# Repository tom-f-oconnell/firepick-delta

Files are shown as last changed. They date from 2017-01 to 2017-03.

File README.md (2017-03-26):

#### Summary / Context

Design and Manufacturing Specifications for [FirePick Delta](http://delta.firepick.org).  If you're a developer wanting to help, the best way to do that is to join the [mailing list](https://groups.google.com/forum/#!forum/firepick) and start a line of communication there.  

This repo only contains the hardware (sch/pcb) and mechanical (3d) files for FirePick Delta.  It inherits software from OpenPnP, Marlin, and FirePick.  Other repo's of interest for FirePick Delta:

* https://github.com/firepick-delta/openpnp
* https://github.com/firepick-delta/Marlin
* https://github.com/firepick1/FireREST
* https://github.com/firepick1/FireBOM

#### Mechanical Assembly Parts Tree, Instructions, and BOM

Please click the link below to navigate the mechanical assembly with our FireBOM wiki documentation system:

[AFPD0001](AFPD0001) FirePick Delta Hacker-Developer Edition

#### Licensing

CC-BY-SA

These files are licensed under [*Creative Commons Attribution-ShareAlike (CC BY-SA)*](https://creativecommons.org/licenses/by-sa/4.0/legalcode).  Commercial use is OK, but you are required under the license conditions to share your changes with the internet, and also credit the FirePick Delta team.

This license lets others remix, tweak, and build upon your work even for commercial purposes, as long as they credit you and license their new creations under the identical terms. This license is often compared to “copyleft” free and open source software licenses. All new works based on yours will carry the same license, so any derivatives will also allow commercial use. This is the license used by Wikipedia, and is recommended for materials that would benefit from incorporating content from Wikipedia and similarly licensed projects. 

[View License Deed](http://creativecommons.org/licenses/by-sa/4.0/) | [View Legal Code](https://creativecommons.org/licenses/by-sa/4.0/legalcode)

#### Contributors
* [@FlyingLotus1983 (Neil Jansen)](https://github.com/FlyingLotus1983)
* [@firepick1 (Karl Lew)](https://github.com/firepick1)
* [@ChristianLerche (Christian Lerche)](https://github.com/ChristianLerche)
* [@daytonpid (Dayton Pidhirney)](https://github.com/daytonpid)
* [@codedetail (Dave Shanklin)](https://github.com/codedetail)
* [@obnauticus (Thomas Kilbride)](https://github.com/obnauticus)
* [@mstegen (Mike Stegen)](https://github.com/mstegen)
* [@mikeanton (Mike Anton)](https://github.com/mikeanton)

#### Maintainers
* [@FlyingLotus1983 (Neil Jansen)](https://github.com/FlyingLotus1983)
* [@firepick1 (Karl Lew)](https://github.com/firepick1)

#### Contributions and Pull Requests

If you'd like to contribute anything back to this repo, please do so via [pull requests](https://help.github.com/articles/using-pull-requests).  

Keep in mind that the Cubify Design files are binary blobs.  Assembly (AD_ASM) files contain filepath links back to dependent solid parts (AD_PRT), and parts contain filepath links back to the assembly.  This makes it extremely tricky to use version control.  You can't just rename files all willy-nilly, or else Cubify will get very angry.  Please excercise caution and contact the FirePick Delta Dev Team via [google group mailing list](https://groups.google.com/forum/#!forum/firepick) before attempting to modify anything of significant nature.

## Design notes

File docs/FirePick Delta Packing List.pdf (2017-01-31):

# Preliminary BOM for FirePick Delta

## Beta Test Kits - Round 1

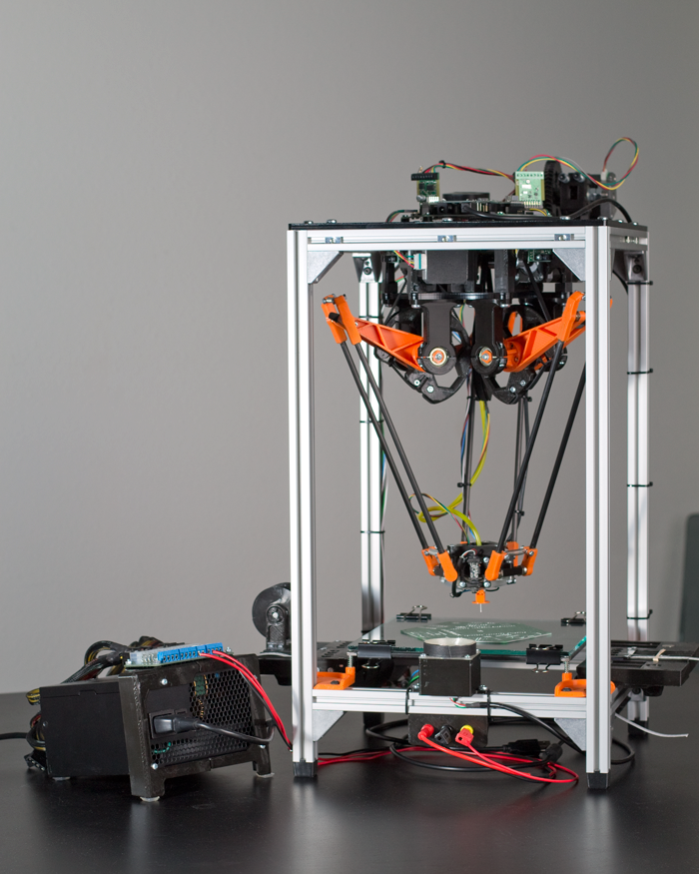
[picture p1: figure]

## Published May 6, 2015

## Heated Bed Assembly

| Part Number | Quantity | Description | Purpose | Barebones?

## Hardware Bag 1

| FBHCS-M5-10L | 8 | Fastener, M5 button-head cap screw, 10mm L | Bed leveling corners | NO
| FFLT-M3-10L | 4 | Fastener, M3 flat-head machine screw, 10mm L | Heated bed PCB attachment | NO
| FNUT-M3 | 4 | Fastener, M3 nut | Heated bed PCB attachment | NO
| FNUT-M4 | 4 | Fastener, M4 nut | Bed leveling corners | NO
| FNUT-M5-HNKK5 | 8 | Extrusion nut, M5 | Attachment to frame extrusion | NO
| FSHCS-M4-30L | 4 | Fastener, M4 socket head cap screw, 30mm L | Bed leveling corners | NO
| FWSH-M3 | 4 | Fastener, M3 flat washer | Heated bed PCB attachment | NO
| FWSH-M4 | 12 | Fastener, M4 flat washer | Bed leveling corners | NO
| MSPRING01 | 4 | Spring, bed leveling | Leveling springs for heated bed | YES
| MCLIP01 | 4 | MCLIP01 - Metal clip for heated bed to glass | Attaches glass to heated bed surface | YES
| MMAG01 | 6 | Magnet, 1/2" dia. x 3/8" L | Install in 3D0028 to act as "pucks" for PCB holding to steel bed | YES
| Zip ties | TBD | 0.1" wide x 6" | Wire management | NO
| N/A | 30" | Wire, twisted pair, heated bed thermistor | Thermistor to EAT0002 wiring | NO
| N/A | 30" | Wire, 18 AWG, yellow, heated bed (ATX power supply '+12V2' to bed) | Heated bed power wiring (~10A) | NO
| N/A | 30" | Wire, 18 AWG, Black, heated bed (EAT0002 to bed) | Heated bed power wiring (~10A) | NO
| N/A | 50" | Wire, 18 AWG, Black, heated bed (EAT0002 to ATX power supply 'GND') | Heated bed power ground wiring (~10A) | NO
| N/A | 2 | Ferrule, thermistor to twisted pair | Ferrule crimps are more reliable than soldering these connections | NO

## Electronics

| EAT0002 | 1 | Modular tool PCB | Connects modular tool to EMC02 | YES
| EL-THERMISTOR | 1 | Thermistor, for heated bed | Temperature sensing element for 3D printing heated bed | NO
| EHB01 | 1 | PCB heated bed | Heated bed for 3d printing | NO

## 3D Printed Pieces

| 3D0052 | 4 | Heated Bed Bracket | Attachment points for the heated bed assembly to the frame | NO
| 3D0028 | 6 | PCB magnet holder | Magnetic "pucks" for holding PCBs | NO

## Plates / Panels

| PG01 | 1 | Glass plate, 1/8" (3mm) x 200mm x 200mm | Glass plate for flat, even surface to print on | YES
| PS01 | 1 | Bed plate, low-carbon steel, waterjet cut | Modular bed that provides magnetic attachment points for SMT PCBs via AD0017 "pucks". Also provides a heat spreading functionality for the heated bed | YES

## Frame Assembly

## Hardware Bag 1

| FBHCS-M5-10L | 48 | Fastener, M5 button-head cap screw, 10mm L | Fasteners for frame extrusion pieces | NO
| FNUT-M5-HNKK | 37 | Extrusion nut, M5 | Holds aluminum extrusion frame peices togeth | NO
| FWSH-M5-SPLIT | 32 | Fastener, M5 flat washer | Fasteners for frame extrusion pieces | NO
| 3D0025 | 4 | Extrusion foot, cast rubber | Custom rubber feet for bottom of machine fra | YES

## Hardware Bag 2 (Brackets)

| XEB505 | 16 | Extrusion 45 degree angle bracket | Corner brackets for frame | NO

## Plates / Panels

| PC01 | 1 | Top plate, acrylic laser cut | Mounting plate for delta mechanism | YES

## Extrusions

| XE2020-260 | 8 | Extrusion, 20x20mm, 260mm long | Horizontal extrusions for frame | NO
| XE2020-500 | 4 | Extrusion, 20x20mm, 500mm long | Vertical extrusions for frame | NO

### Delta Mechanism

| Part Number | Quantity | Description | | Barebones?

### Hardware Bag 1

| DB608 | 6 | Bearing, 608 | Ball bearings for delta arms | NO
| DGB383 | 3 | GT2 belt, 383mm L | NOTE: This may be in one continuous length rather than three separate pieces | NO
| DGP16T | 3 | GT2 pulley, 16 teeth, 5mm bore | Aluminum pulley goes on end of NEMA 17 stepper motor | NO
| FSET-M3-6L | 6 | Fastener, M3 set screw | NOTE: These may already be in the 16T GT2 pulley | NO
| FBHCS-M5-14L | 12 | Fastener, M5 button-head cap screw, 14mm L | These connect the 3D00456 stepper mounts to the frame PC01 plate. | NO
| FBHCS-M5-20L | 12 | Fastener, M5 button-head cap screw, 20mm L | These connect the 3D0001a bearing blocks to the 3D00456 stepper mounts | NO
| FFLT-M3-12L | 3 | Fastener, M3 flat-head machine screw, 12mm L | This fastener holds the GT2 belt to the 150T pulley. | NO
| FNUT-M3 | 54 | Fastener, M3 nut | | NO
| FNUT-M5 | 24 | Fastener, M5 nut | Go inside 3D00456 nut traps | NO
| FPAN-M3-10L | 12 | Fastener, M3 pan-head machine screw, 10mm L | | NO
| FPAN-M3-12L | 3 | Fastener, M3 pan-head machine screw, 12mm L | This fastener holds the GT2 belt to the 150T pulley. | NO
| FPAN-M3-20L | 21 | Fastener, M3 pan-head machine screw, 20mm L | 12 are used to attach the 608 bearing block caps 6 are used to attach the EOPTO01 to the 3D00456. 3 are used to attach the 3D0007 optical interruptors to the 3D0003a delta arms | NO
| FPAN-M3-30L | 12 | Fastener, M3 pan-head machine screw, 30mm L | These hold the 3D0003a arms to the 3D0002b pulleys | NO
| FPAN-M3-50L | 6 | Fastener, M3 pan-head machine screw, 50mm L | These hold the 3D0003b nuts to the 608 bearings and the 3D0003a delta arms | NO
| FWSH-M3 | 6 | Fastener, M3 flat washer | These go between the 3D0003b nuts and the 608 bearings on the delta arm assemblies | NO

### Hardware Bag #2

| DBS-0.375-10L-HEX | 6 | Ball stud, 3/8" dia, M3x10 | Delta mechanism bearings | YES

### Plates / Panels

| PC03a | 1 | Delta motor plate (Acrylic laser-cut) | Center plate between motors and delta pulleys/arms/bearings | YES

### Electronics

| EOPTO01 | 3 | Optical endstop board | Homing switches (these are optical interruptor type) | YES

### 3D Printed Pieces

| 3D0001a | 6 | Delta motor Assembly - 608 bearing block | Black. Bearing blocks for delta arms. | NO
| 3D0002b | 3 | Delta motor assembly - Pulley, 150 teeth | Black. Large pulley connected to 3D0003a/b arms | NO
| 3D0003a | 6 | Delta motor assembly - Delta arm 90mm | Orange. Delta mechanism upper arm | NO
| 3D0003b | 6 | Delta motor assembly - Delta arm 90mm nut | Orange. Nut to allow 608 bearings to be attached to 3D0003a via M3 hardware. | NO
| 3D0004 | 6 | Delta motor Assembly - 608 bearing block caps | Black. Caps for bearing blocks. | NO
| 3D0007 | 3 | Delta motor assembly - Limit switch interruptor | Black. This is attached between the 3D0003a arms and acts as an interruptor to the optical limit switch | NO
| 3D0456 | 3 | Delta stepper mount | Black. Mounts steppers to PC01 and PC03a middle plate | NO

### Big heavy stuff

| EM-ST17 | 3 | Stepper motor, NEMA 17 | Stepper motors for delta mechanism | NO

## Motion Controller Assembly

## Hardware Bag 1

| FNUT-M3 | 14 | FNUT-M3 | 6 go in the 3D0021, 8 go in the 3D0015a | NO
| FPAN-M3-25L | 6 | FPAN-M3-25L | For attaching PC04a to EMC02 and the PC01 panel via standoffs | NO
| FPAN-M3-20L | 8 | FPAN-M3-20L | Fasteners for 3D0021 and PC04a | NO

## Electronics

| EMC02 | 1 | EMC02 motion controller board | Motion controller breakout board | YES
| N/A | 17 | Shunt / Shorting jumper, 0.1" | Configuration jumpers for EMC02 module | YES
| EL-ARDUINO-MEGA256 | 1 | Arduino Mega 2560 | Microprocessor loaded with Arduino / Marlin firmware | NO
| N/A | 1 | USB cable, "A" to "B" | For Arduino | NO
| EL-STEPSTICK | 3 | Stepstick (stepper motor driver module) | Stepper motor driver module | YES

## Wiring

| N/A | 3 | Stepper motor cable, 4-pin, ~145mm | | NO
| N/A | 3 | Endstop cable, ~95mm L | | NO

## 3D Printed Pieces

| 3D0021 | 4 | EMC01 Modular tool card-cage | Card cage for the modular tools. Prevents them from being plugged in backwards, and provides mechanical integrity | NO
| 3D0015a | 3 | EMC02 mounting plate | Provides a | NO
| FSTN-M3-16L-UNTHRE | 6 | Standoffs (spacers) | For mounting the PC04a plate onto the EMC02 assembly | NO

## Plates / Panels

| PC04a | 1 | EMC02 cover plate, laser cut acrylic | Cover plate | YES

| FPAN-M5-8L | 2 | Fastener, M5 pan-head machine screw, 8mm L | These attach the up-looking camera module to the frame | NO
| FPAN-M3-8L | 4 | Fastener, M3 pan-head machine screw, 8mm L | These attach the LED diffuser ring to the camera module housing | NO
| FPAN-M2-8L | 4 | Fastener, M2 pan-head machine screw, 8mm L | These attach the camera module to the housing | NO
| FNUT-M3 | 4 | Fastener, M3 nut | These attach the LED diffuser ring to the camera module housing | NO
| FNUT-M2 | 4 | Fastener, M2 nut | These attach the camera module to the housing | NO
| FNUT-M5-HNKK5 | 2 | Extrusion nut, M5 | These attach the up-looking camera module to the frame | NO
| N/A | 42" | Wire, 24 AWG, red | Up-looking camera LED ring +5V power | NO
| N/A | 42" | Wire, 24 AWG, black | Up-looking camera LED ring GND | NO
| N/A | 42" | Wire, 24 AWG, white | Up-looking camera LED ring ON signal | NO
| N/A | 6 | Crimp pin, 0.1" for rectangular header | Crimp pin for cable | NO
| N/A | 2 | Rectangular header, 3-pin non-polarized | Rectangular housing for cable | NO
| N/A | 7 | Zip ties, 0.1" wide (long enough to zip tie to frame) | Cable management | NO

### 3D printed parts

| 3D0026b | 1 | Up-looking camera housing base (black PLA) | Provides an enclosure for the camera, with an attach point for an LED ring light | NO
| 3D0030b | 1 | Up-looking camera housing diffuser (clear / natural PLA) | Acts as a diffuser for the ring light. Attaches to the 3D0026b base. | NO

### Electronics

| EL-CAM-ELP-USB100W03M | 1 | EL-CAM-ELP-USB100W03M | Up-looking camera module. | YES
| N/A | 1 | USB cable for the ELP camera | This USB cable should be included with the ELP camera. | YES

### ELED02 Ring Light Kit

| ELED02 | 1 | Up-looking camera ring light PCB | LED Ring light for improving down-looking camera effectiveness. Note:
| N/A | 16 | LED, 1206, red | This is a kit intended to be used during the testing phases of the SMT pick and place functionality of the machine.
| N/A | 8 | Resistor, 0805, 120 ohm
| N/A | 1 | MOSFET, SOT-23, BSS138 | | YES
| N/A | 1 | Resistor, 10K
| N/A | 1 | Capacitor, 100 uF
| N/A | 1 | Rectangular header, male, right-angle, 3-pin, 0.1" offset

### Up-Looking Camera

| FNUT-M5-HNKK5 | 2 | Extrusion nut, M5 | Vacuum pump frame mount and clamp | NO
| FPAN-M5-14L | 1 | FPAN-M5-14L | Vacuum pump mount clamp | NO
| FBHCS-M5-14L | 1 | FBHCS-M5-14L | Vacuum pump mount to frame | NO
| DTB-0.0625-0.1875 | 1 | Tubing coupler, barbed, 1/16" to 3/16" | Adapt vacuum pump tubing size down to smaller size | YES
| FFLT-M5-10L | 3 | Fastener, M5 flat-head machine screw, 10mm L | Modular tool changer points | NO
| FNUT-M5 | 3 | Fastener, M5 nut | Modular tool changer points | NO
| FPAN-M2-5L | 4 | Fastener, M2 pan-head machine screw, 5mm L | NEMA 8 motor to 3DAT0021a | NO
Nozzle Bag
| TBD-Large nozzle | 1 | Large nozzle tip, machined 12L40 steel | Vacuum tip for large SMT parts (electrolytic caps, etc) | YES
| TBD-Small nozzle | 1 | Small nozzle tip, machined 12L40 steel | Vacuum tip for small SMT parts (resistors, etc) | YES
| TBD-Coupler | 1 | Coupler, machined aluminum | This is permanently attached to the hollow-shaft NEMA 8 motor, and allows various tips to be installed | YES
| TBD | 1 | Set screw, M3 x 5mm | Used to attach the coupler ot the NEMA 8 hollow shaft motor | YES
| TBD | 1 | O-ring | Goes on the aluminum shaft, provides a lock-fit and air-tight connection between the coupler and the tips | YES

Electromechanical

| EM-ST08-HOLLOW | 1 | Stepper motor, NEMA 8 hollow-shaft | SMT nozzle part rotation | YES
| VP01 | 1 | Diaphragm vacuum pump, 12V | Vacuum source | YES
3D printed parts
| | 1 | Vacuum pump mount | Mount vacuum pump to frame | NO
| 3DAT0021a | 1 | Modular tool mount for SMT, NEMA 8 motor | Holds NEMA 8 motor | NO
Electronics
| EAT0004 | 1 | Modular tool PCB | Connects modular tool to EMC02 | YES
Misc.
| MFOAM01 | 1 | Foam strip | Vibration damper for diaphragm pump | YES
| DTS-0.1875ID-0.3125OD-150L | 1 | Tubing, silicone, 3/16" ID, 5/16" OD, 150mm L | Attaches to diaphragm pump | NO
| DTS-0.0625ID-0.1875OD-500L | 1 | Tubing, silicone, 1/16" ID, 3/16" OD, 500mm L | Attaches to NEMA 8 hollow-shaft motor | NO
| N/A | 18" | Wire, 24 AWG, red | SMT modular tool, NEMA 8 motor extension | NO
| N/A | 18" | Wire, 24 AWG, green | SMT modular tool, NEMA 8 motor extension | NO
| N/A | 18" | Wire, 24 AWG, yellow | SMT modular tool, NEMA 8 motor extension | NO
| N/A | 18" | Wire, 24 AWG, black | SMT modular tool, NEMA 8 motor extension | NO
| N/A | 14" | Wire, 24 AWG, red | SMT modular tool, diaphragm pump | NO
| N/A | 14" | Wire, 24 AWG, black | SMT modular tool, diaphragm pump | NO
| N/A | 1 | Cable, NEMA 8 stepper motor | NOTE: This comes with the NEMA 8 motor | NO
| N/A | 4 | Zip ties | 1x for holding silicone tubing to NEMA 8 motor. 3 for wire management | NO
| N/A | 5mm | Heat shrink tubing - 1" unshrunk | Wrap around stepper motor | NO
| N/A | 3x 10mm | Heat shrink tubing - 1/8" dia unshrunk | Extension wiring on stepper motor cabling | NO
| N/A | 2x 15mm | Heat shrink tubing - 3/16" dia unshrunk | Diaphragm pump wiring | NO

SMT Modular Tool

| FHEX-M8-60L-HOBBED | 1 | Hobbed bolt | Hobbed bolt for the 3d printer extruder (hobbed portion pushes the plastic into the hotend) | NO
| FNUT-M3 | 1 | Fastener, nut, M3 | This goes in the guidler hinge nut trap | NO
| FNUT-M8 | 1 | Fastener, nut, M8 | This goes on the end of the hobbed bolt (NOTE: This is optional, as you can just use the nylock nut, but this will make unscrewing the nylock a lot easier) | NO
| FPAN-M3-25L | 3 | Fastener, M3 pan-head machine screw, 25mm L | 2 for the J-Head groove mount clamp. 1 for the Guidler hinge. | NO
| FPAN-M3-8L | 3 | Fastener, M3 pan-head machine screw, 8mm L | Attaches the NEMA 17 stepper motor to the Wade extruder | NO
| FSET-M8-20L | 1 | Set screw, M8, 20mm L | 608 bearing rotates around this in the guidler | NO
| FWSH-M3-SPLIT | 3 | Fastener, washer, M3, split-lock | Optional; These can be used on the NEMA 17 stepper motor attachment screws to ensure the motor does not vibrate loose | NO
| FWSH-M8 | 1 | Fastener, washer, M8 | This goes on the outside of the 608 bearing, before the M8 nut | NO
| MSPRING01 | 2 | Extruder spring | For the guidler. They go over the FSHCS-M4-60L screws | YES
| FSHCS-M4-60L | 2 | Fastener, socket-head cap screw, M4, 60mm L | Guidler tensioning | NO
| FWSH-M4 | 4 | Fastener, washer, M4 | These go over the FSHCS-M4-60L screws, on both sides of the springs | NO
| FNUT-M4 | 2 | Fastener, nut, M4 | These go into the nut traps in the 3DAT0001a, for the guidler tensioning screws | NO
| FNUT-M8-LOCK | 1 | Fastener, M8, nut, nylock | The M8 lock nut keeps the large herringbone gear and hobbed bolt from coming loose | NO
| FNUT-M5-HNKK5 | 1 | Extrusion nut | This attaches the Wade extruder to the extruded frame | NO
| FBHCS-M5-10L | 1 | Fastener, button-head cap screw, M5, 10mm L | This attaches the Wade extruder to the extruded frame | NO
| VF01 | 2 | Embedded Bowden Couplings - For Plastic (1.75mm Filament) | Bowden tubing push-to-fit connector (1 for Wade extruder, 1 for the modular tool). NOTE: There are two pieces to each fitting: The outside coupling with the spiky barbs, and the fitting that goes inside it | YES
| FFLT-M5-10L | 3 | FFLT-M5-10L | Modular tool changer points | NO
| FNUT-M3 | 2 | FNUT-M3 | Clamp for J-Head groove mount | NO
| FNUT-M5 | 3 | FNUT-M5 | Modular tool changer points | NO
Misc.
| DTPTFE-4OD-2ID-500L | 500mm | Bowden tube, PTFE (Teflon), 4mm OD, 2mm ID | For Bowden tube | NO
| N/A | 30" | Wire, 24 AWG, red | Hotend heating element | NO
| N/A | 30" | Wire, 24 AWG, black | Hotend heating element | NO
| N/A | 30" | Wire, twisted pair, 26-28 AWG | hotend thermistor | NO
| N/A | 2 | Ferrule, thermistor to twisted pair | Because ferrules are more reliable than soldering for this connection | NO
| N/A | 2 | Ferrule, resistor to 24 AWG wire | Because ferrules are more reliable than soldering for this connection | NO
| N/A | 2x | Heat shrink, PTFE (Teflon) | To cover the hotend's crimped ferrules | NO
| N/A | 2x | Heat shrink, for thermistor leads | To cover the thermistor's crimped ferrules | NO
| N/A | 200mm | Kapton tape, ~12mm wide | NOTE: Doesn't ship with the kit | NO
| N/A | 9 | Zip ties (small / 6") | Wire management | NO
| N/A | 2x 35mm | Heat shrink tubing, 3/8" dia | For wiring and bowden tubing securing (both ends) | NO
| N/A | 500mm | Techflex sleeving (optional) | Optional. Covers Bowden tube and wiring | NO
| N/A | 2x 35mm | Fiberglass sleeving | Thermistor wiring / insulation (between glass bead and crimped ferrule) | NO

## Electromechanical

| EM-ST17 | 1 | EM-ST17 | Stepper motor, NEMA 17 | NO
| DB608 | 3 | Bearing, 608 | Bearing, 608 | NO

## 3D printed parts

| 3DAT0001a | 1 | Wade extruder body | Extruder housing. Based on Greg's Wade reloaded extruder assembly (http://www.thingiverse.com/thing:18379) | NO
| 3DAT0002 | 1 | Wade large gear (herringbone) | Large herringbone gears for extruder | NO
| 3DAT0003 | 1 | Wade small gear (herringbone) | Small herringbone gear for extruder | NO
| 3DAT004 | 1 | Guidler | For extruder | NO
| 3DAT0027 | 1 | Extruder latch | Inspired by the Lulzbot extruder latch. Makes it easier to secure the guidler | NO
| 3DAT0012 | 1 | 3DAT0012 - 3D printer mount | Black - Modular tool housing (Conical taper part) | NO
| 3DAT0017 | 1 | 3DAT0017 - 3D printer mount - J-Head (top) | Orange - Modular tool housing (top part, to secure the J-Head groove mount) | NO
| 3DAT0018 | 1 | 3DAT0018 - 3D printer mount - J-Head (clamp) | Black - Modular tool housing (Clamp for 3DAT0017 for J-Head groove mount) | NO
| 3DAT0028 | 1 | Wade extruder hobbed bolt spacer - 8.5mm | This is a spacer for getting the hobbed portion of the bolt to line up with the Wade extruder's filament hole. It is intended for hobbed bolts that have a hobbed position 30mm away from the bolt head's mating side | NO

## Electronics / Hotend Components

| EAT0004 | 1 | Modular tool PCB | Connects modular tool to EMC02 | YES
| EL-STEPSTICK | 1 | StepStick A4988 stepper driver PCB module with heatsink | Plugs into EAT0004 and drives the NEMA 8 hollow-shaft stepper motor | NO
| N/A | 3 | Shunt / Shorting jumper, 0.1" | These set the microstepping on the stepstick | NO
| 3DJH0001 | 1 | Genuine J-Head Mk V-BV, 0.40mm nozzle, for 1.75 filament | Genuine hotend from hotends.com (Reifsnyder Precision Works) | NO
| 3DJH0002 | 1 | Resistor, 5.6 ohm, 5W, 1% | UB5C-5.6-ND | NO
| 3DJH0003 | 1 | Thermistor, 100k, 3% (Semitec 104GT-2) | Temperature sensing element for 3D printing heated bed | NO

## 3D Printing Modular Tool

| Part Number | Quantity | Description | Purpose | Barebones

| FPAN-M3-25L | 4 | Fastener, pan-head machine screw, M3, 25mm L | Holds the EPWR01 to the 3D0053 frame. | NO
| FPAN-6_32-0.3125L | 4 | Fastener, pan-head machine screw, 6-32 x 5/16" L | These attach the power supply to the 3D0053 frame. The power supply that ships with the kit does not use metric M3 screws; they use the older imperial 6-32 thread size. | NO
| FNUT-M3 | 4 | Fastener, nut, M3 | Holds the EPWR01 to the 3D0053 frame. | NO
| MFEET01 | 4 | Square 12.5mm adhesive rubber feet | These go under the power supply and the 3D0053 frame to keep it from sliding around the workbench | NO
| N/A | 50" | Wire, 18 AWG, red | +5V power to EMC02 board | NO
| N/A | 50" | Wire, 18 AWG, black | GND to EMC02 board | NO
| N/A | 50" | Wire, 18 AWG, yellow | +12V power to EMC02 board | NO
| N/A | 50" | Wire, 24 AWG, green | PS_ON signal | NO

## Plates / Panels

| PC04 | 1 | ATX cover plate | Plate to cover the EPWR01 PCB | YES

## Electronics

| EPWR01 | 1 | Power supply breakout board | Breakout board that brings the DC power voltages and signals to screw terminals | YES
| N/A | 1 | Rectangular header, male, right-angle, 0.1" offset | Optional. May be used with either the shunt / shorting block or external cabling to turn the power supply on or off. | NO
| N/A | 1 | Shunt / shorting block, 0.1" offset | Optional. May be used with the rectangular 2-pin header to turn the power supply on or off. | NO

## 3D Printed Pieces

| 3D0053 | 1 | External ATX supply frame | Optional; This frame makes using the ATX power supply a lot more convenient | NO
| FSTN-M3-14L-UNTHREADED | 4 | Standoff, 3D printed, for M3 screw, 14mm long, unthreaded | For attaching the PC04 ATX cover plate to the 3D0053 frame | NO

## Big Stuff

| EL-PWR-ATX | 1 | ATX power supply, 480W | Provides DC +12V and +5V power to the machine | NO

## ATX Power Supply

## End Effector and Arms

## Hardware Bag 1

| DBS-0.375-10L-HEX | 6 | Ball stud, 3/8" dia, M3x10 | Delta mechanism bearings | YES
| FNUT-M3 | 21 | Fastener, M3 nut | End effector (4*3 for end effector side mounts. 3 for holding the two end effector 3d printed halves together. | NO
| FPAN-M3-12L | 4 | Fastener, pan-head machine screw, M3, 12mm L | These hold the 30mm fan into the end effector | NO
| MMAG04 | 3 | Magnet, 0.25" dia x 0.25"L | Modular tool changing system attachment point | YES
| FPAN-M3-8L | 4 | Fastener, pan-head machine screw, M3, 8mm L | These hold the camera mount onto the end effector | NO
| FPAN-M3-10L | 12 | Fastener, pan-head machine screw, M3, 10mm L | These hold the tension springs into the delta arms | NO
| FPAN-M3-20L | 3 | Fastener, pan-head machine screw, M3, 20mm L | These hold the two halves of the end effector together | NO

## Electronics / Electromechanical

| EL-CAM-ENDO | 1 | Endoscopic USB camera module | Vision for SMT pick and place | YES
| EL-USB-CABLE | 1 | USB cable | Attaches to endoscopic USB camera module | YES
| EL-FAN-30MM | 1 | EL-FAN-30MM | Cooling for modular tools (3D print hotend, etc) | NO

## 3D printed parts

| 3DAT0011a | 1 | End effector - ATC hub (top) | Top half of end effector | NO
| 3DAT0010a | 1 | End effector - ATC hub (bottom) | Bottom half of end effector. Printed in clear / natural PLA. Acts as a diffuser for the ring light assembly. | NO
| 3DAT0015c | 1 | Camera-to-end-effector mount - downward endocam | Attachment point for the camera | NO

## ELED01 Ring Light Kit

| ELED01 | 1 | End effector camera ring light PCB | LED Ring light for improving down-looking camera effectiveness. Note: This is a kit intended to be used during the testing phases
| N/A | 16 | LED, 1206, white | of the SMT pick and place functionality of the machine.
| N/A | 8 | Resistor, 0805, 120 ohm
| N/A | 1 | MOSFET, SOT-23, BSS138 | | YES
| N/A | 1 | Resistor, 10K
| N/A | 1 | Capacitor, 100 uF
| N/A | 1 | Rectangular header, male, right-angle, 3-pin, 0.1" offset

## Cabling for Ring Light

| N/A | 30" | Wire, 24 AWG, red | End effector LED ring +5V power | NO
| N/A | 30" | Wire, 24 AWG, black | End effector LED ring GND | NO
| N/A | 30" | Wire, 24 AWG, white | End effector LED ring ON signal | NO
| N/A | 6 | Crimp pin, 0.1" for rectangular header | Crimp pin for cable | NO
| N/A | 2 | Rectangular header, 3-pin non-polarized | Rectangular housing for cable | NO

## Delta Arms

| AD0003b | 6 | Delta rods, carbon fiber tubing with 3D printed end cups | NOTE: These have been glued together in a special jig to ensure exactly 270mm center-to-center. | YES
| MSPRING02 | 6 | Tension springs | These hold the delta arms into the ball-studs | YES

## Cabling for Fan

| N/A | 1 | Cable assembly for 30mm fan. Red/black wires with rectangular 2-pin 0.1" offset housing on one end, and stripped/tinned ends on other side. ~1 meter long | For extending the 30mm fan from the end effector to the EMC02 PCB | NO
| N/A | 2x 15mm | Heat shrink tubing, 1/8" dia unshrunk | For fan cable assembly | NO

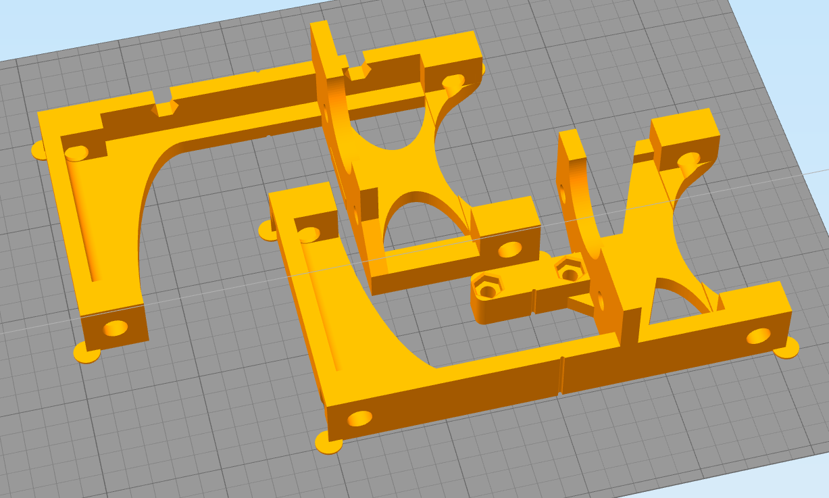
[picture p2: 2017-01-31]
docs/STL images/3D0456 Delta stepper mount.png

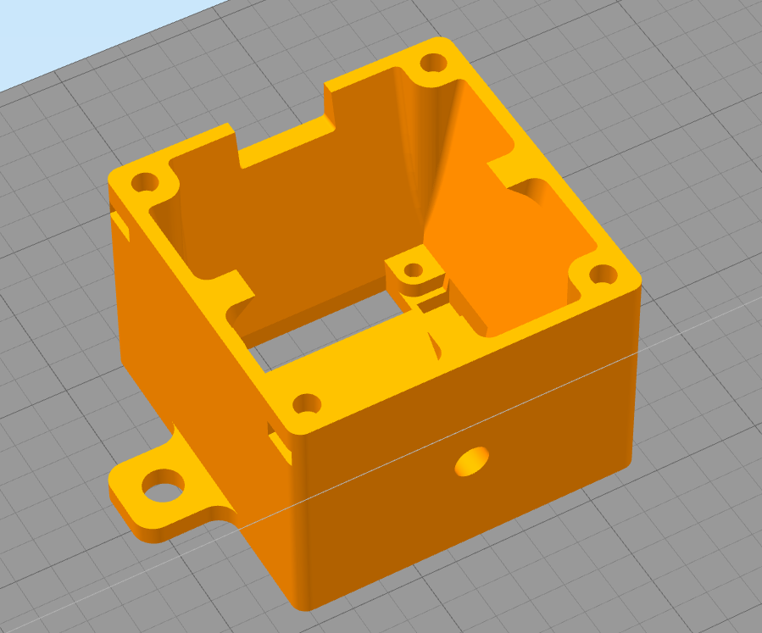
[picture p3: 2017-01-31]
docs/STL images/3D0026b - Up-looking camera housing base - ELP-USB100W03M.png

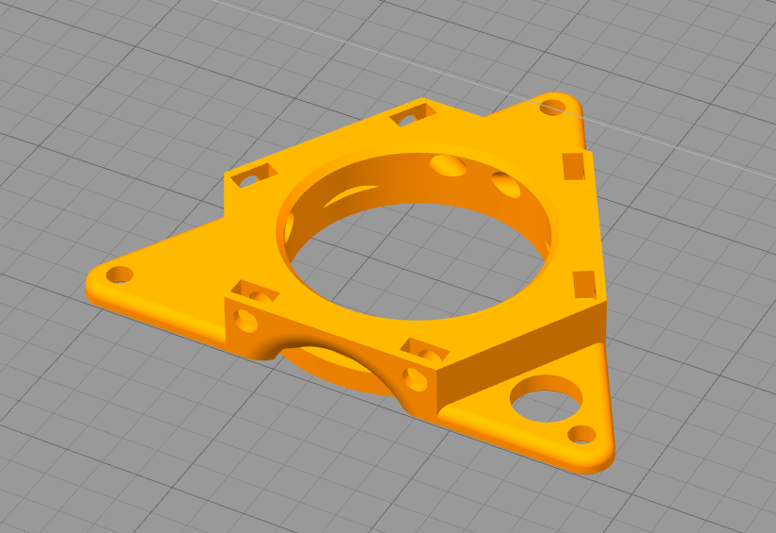
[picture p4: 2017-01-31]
docs/STL images/3DAT0010a - End effector - ATC hub (bottom).png

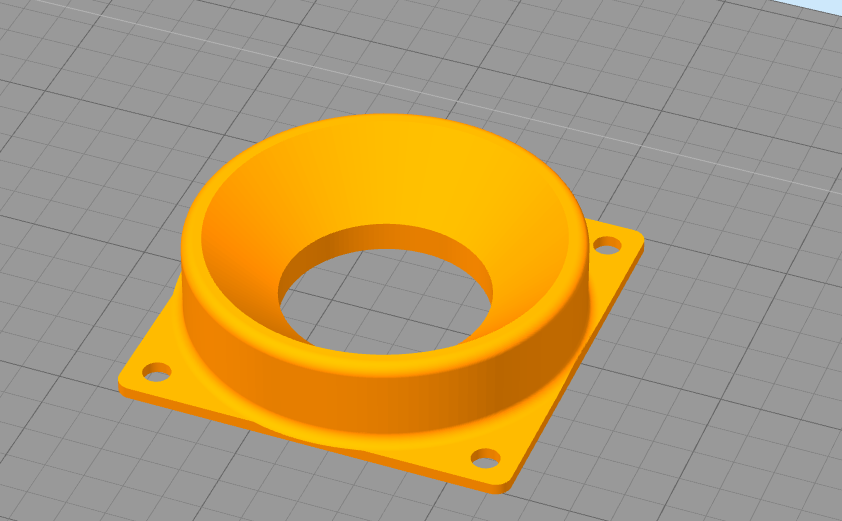
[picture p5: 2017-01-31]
docs/STL images/3D0030b - Up-looking camera housing diffuser - ELP-USB100W03M.png

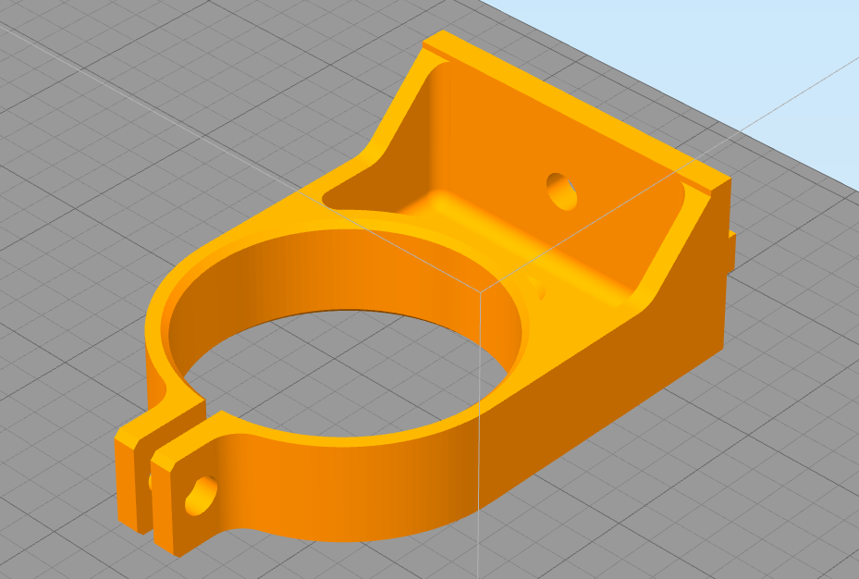
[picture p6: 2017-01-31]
docs/STL images/3DAT0005 - Vacuum pump mount.png

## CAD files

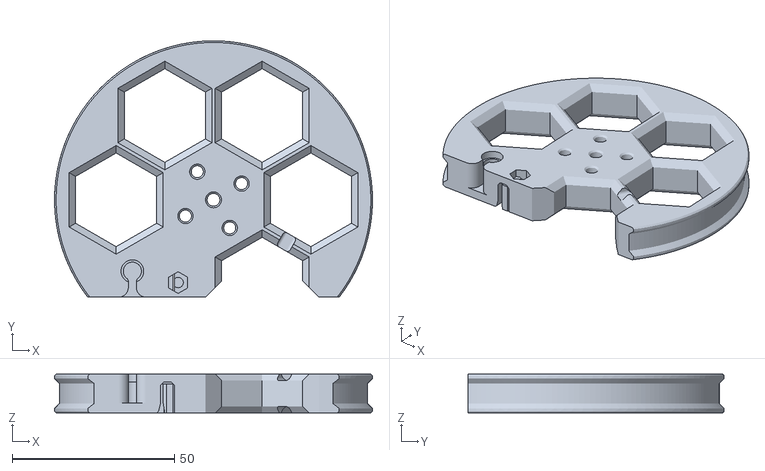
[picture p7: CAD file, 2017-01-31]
production/3D printed pieces - STL - Black/3D0002b - Delta motor assembly - Pulley (150T).stl
98.0 x 79.0 x 12.0

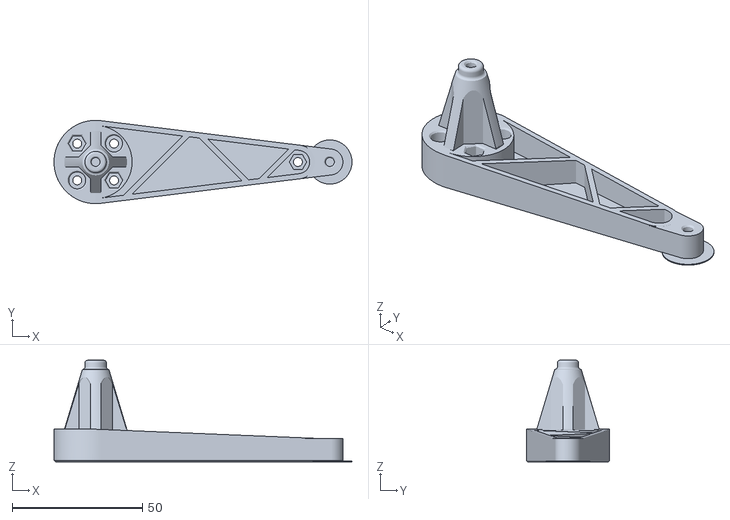
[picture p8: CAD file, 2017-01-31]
production/3D printed pieces - STL - Orange/3D0003a - Delta motor assembly - Delta arm 90mm.stl
114.5 x 32.0 x 39.0

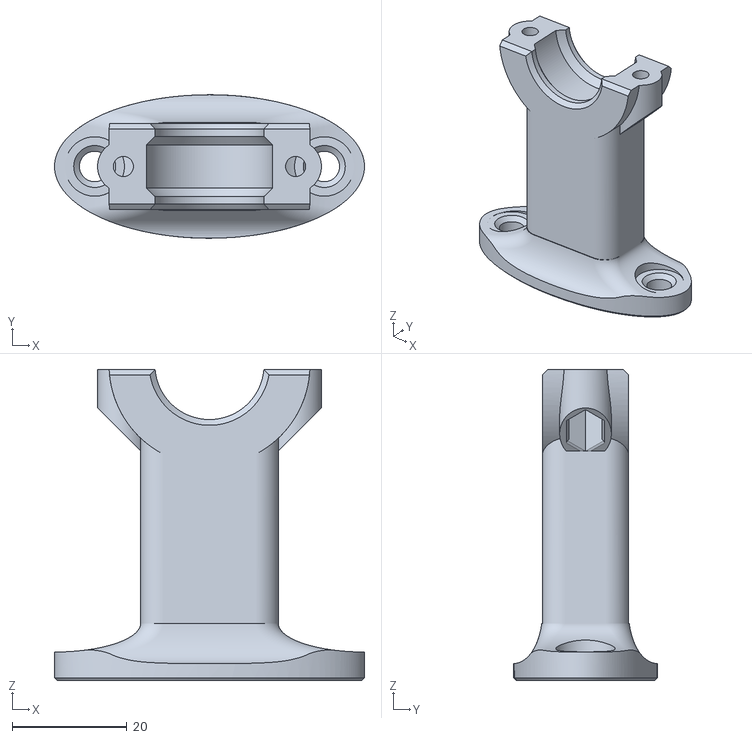
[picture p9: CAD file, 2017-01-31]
production/3D printed pieces - STL - Black/3D0001a - Delta motor Assembly - 608 bearing block.stl
54.0 x 25.0 x 54.3

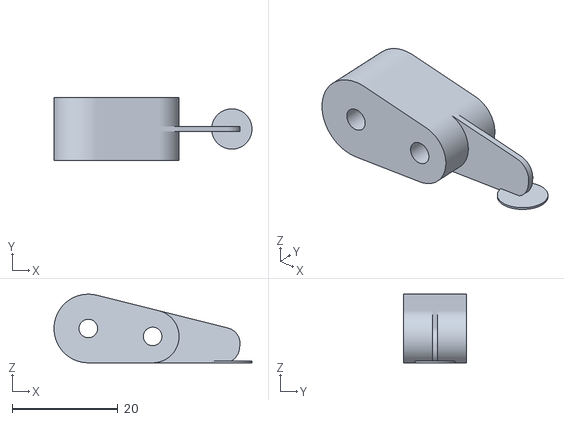
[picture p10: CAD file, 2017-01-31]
production/3D printed pieces - STL - Black/3D0007 - Delta motor assembly - Limit switch interruptor.stl
37.5 x 12.0 x 13.0

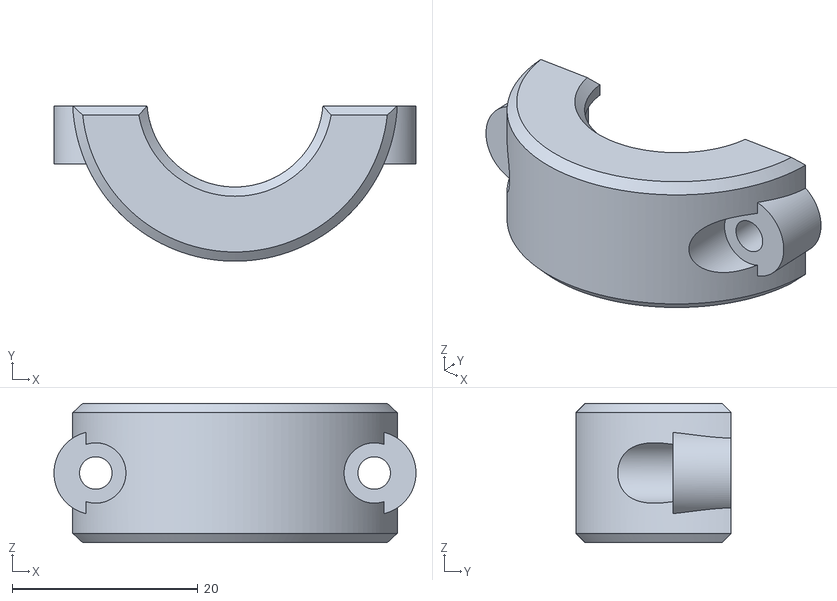
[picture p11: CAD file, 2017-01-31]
production/3D printed pieces - STL - Black/3D0004 - Delta motor Assembly - 608 bearing block caps.stl
39.0 x 16.8 x 15.0

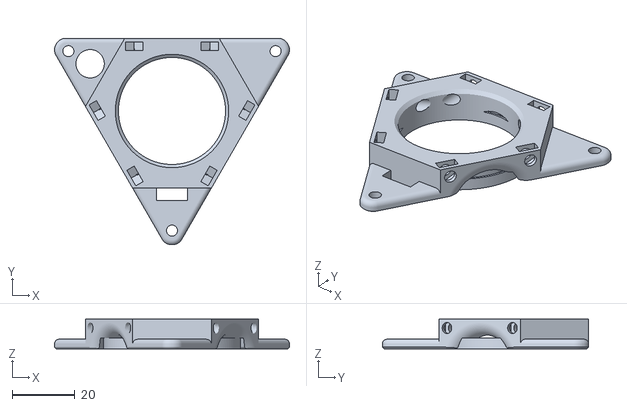
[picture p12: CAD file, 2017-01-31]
production/3D printed pieces - STL - Clear/3DAT0010a - End effector - ATC hub (bottom).stl
74.7 x 65.6 x 9.40

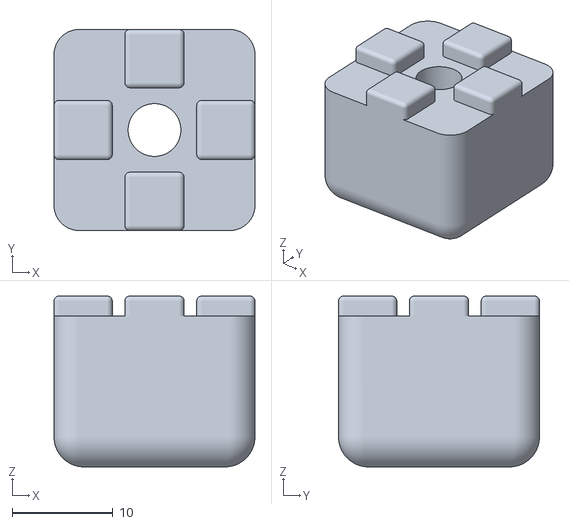
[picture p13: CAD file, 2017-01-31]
production/3D printed pieces - STL - Flexy/3D0025 - Rubber Foot.stl
20.0 x 20.0 x 17.0

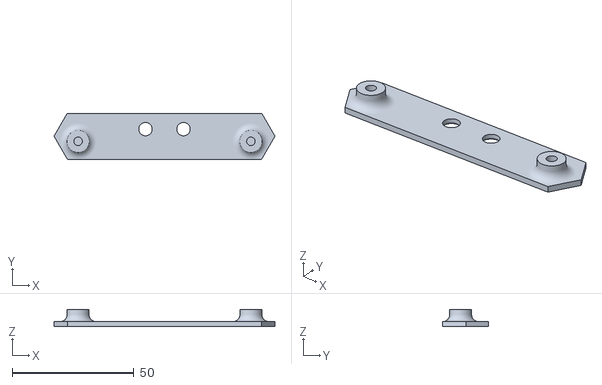
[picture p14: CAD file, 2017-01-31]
production/3D printed pieces - STL - Black/3D0015a - EMC02 mounting plate.stl
90.8 x 19.0 x 7.00

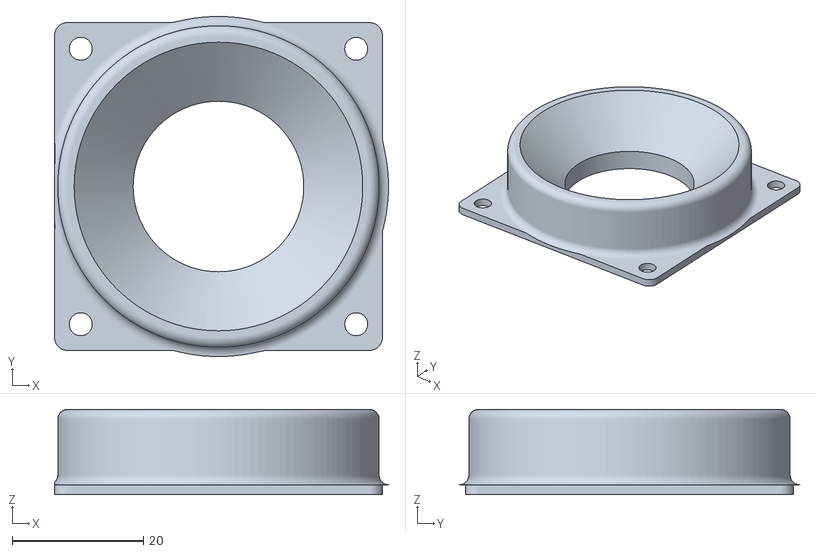
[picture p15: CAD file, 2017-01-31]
production/3D printed pieces - STL - Clear/3D0030b - Up-looking camera housing diffuser - ELP-USB100W03M.stl
50.9 x 51.9 x 13.0

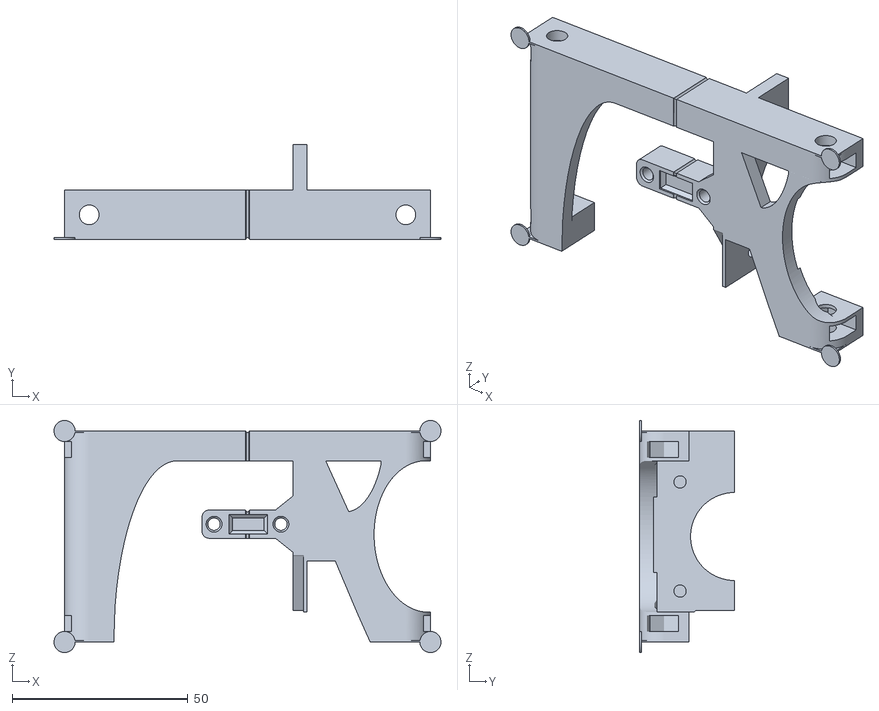
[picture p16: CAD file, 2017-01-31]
production/3D printed pieces - STL - Black/3D0456a Delta stepper mount.stl
110.0 x 27.0 x 66.0

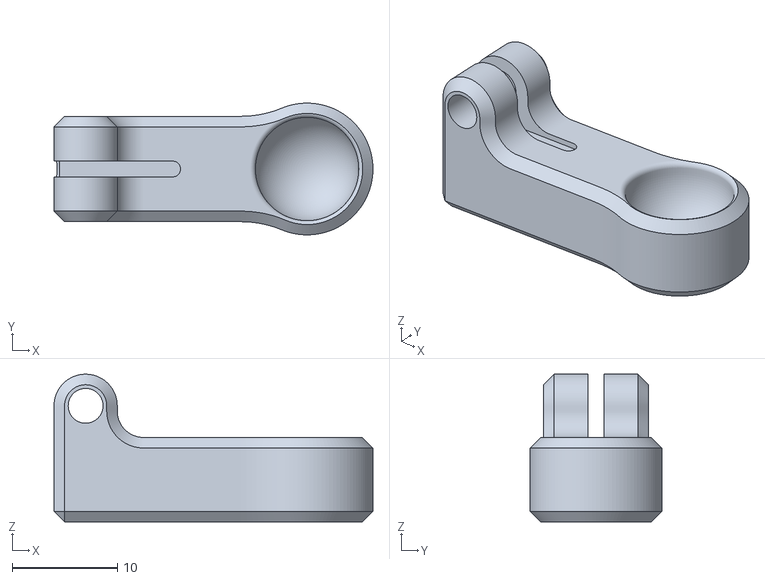
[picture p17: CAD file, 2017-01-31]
production/3D printed pieces - STL - Orange/3D0023 - Delta rods - Lower spring-socket holder.stl
30.2 x 12.5 x 14.0

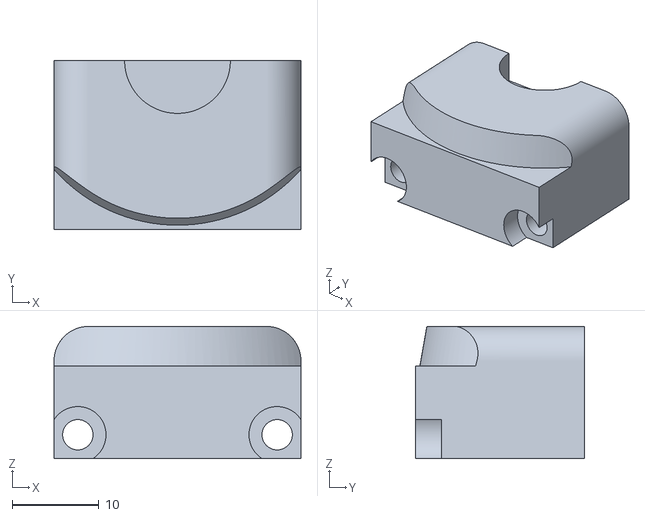
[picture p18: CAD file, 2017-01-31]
production/3D printed pieces - STL - Black/3DAT0018a - 3D printer mount - J-Head (clamp).stl
28.5 x 19.5 x 15.3

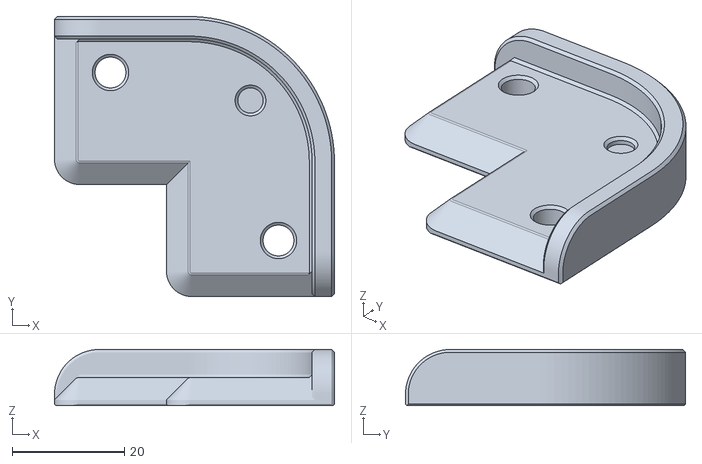
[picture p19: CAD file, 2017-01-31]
production/3D printed pieces - STL - Orange/3D0052 - Heated Bed Bracket.stl
50.0 x 50.0 x 10.0

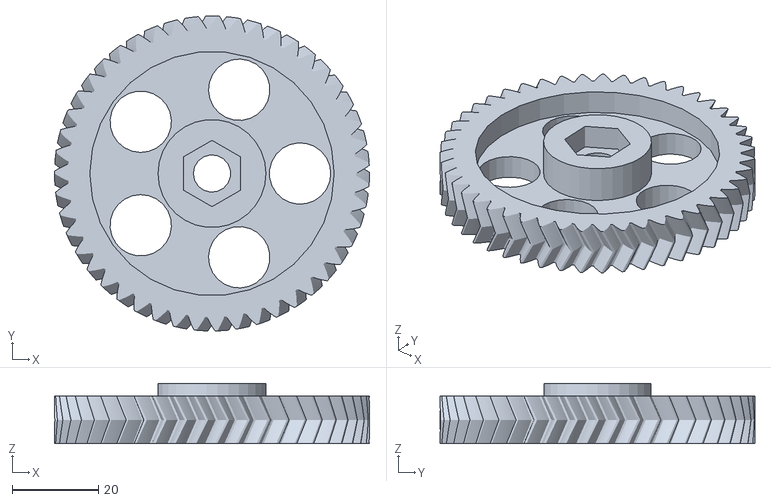
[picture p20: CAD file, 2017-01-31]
production/3D printed pieces - STL - Black/3DAT0002 - Wade large gear (herringbone).stl
73.0 x 73.0 x 14.0

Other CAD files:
production/3D printed pieces - STL - Orange/3DAT0015c - Camera-to-end-effector mount - downward endocam.stl
production/3D printed pieces - STL - Black/FSTN-M3-16L-UNTHREADED.stl
production/3D printed pieces - STL - Orange/3DAT0017 - 3D printer mount - J-Head (top).stl
production/3D printed pieces - STL - Black/vial_funnel.stl
production/3D printed pieces - STL - Black/1in_8020_m3_channel_nut.stl
production/3D printed pieces - STL - Black/3D0010a - Extrusion nut (M3).stl
production/3D printed pieces - STL - Black/3D0021 - EMC01 Modular tool card-cage.stl
production/3D printed pieces - STL - Black/3D0026b - Up-looking camera housing base - ELP-USB100W03M.stl
production/3D printed pieces - STL - Black/3D0028 - PCB magnet holder.stl
production/3D printed pieces - STL - Black/3D0456 Delta stepper mount (unibody).stl
production/3D printed pieces - STL - Black/3D0456ab Delta stepper mount.stl
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

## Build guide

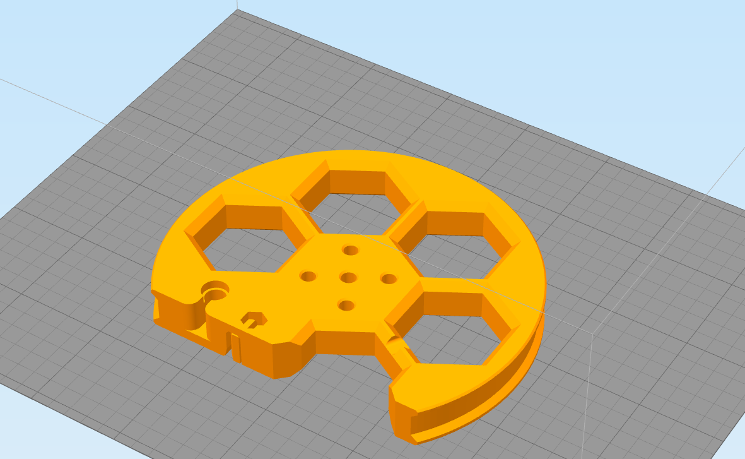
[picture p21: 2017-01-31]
docs/STL images/3D0002b - Delta motor assembly - Pulley (150T).png
